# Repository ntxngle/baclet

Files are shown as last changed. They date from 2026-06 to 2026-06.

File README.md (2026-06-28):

# baclet
## What and Why

A mobile, battery powered trinket that measures BAC (Blood AlcoholContent) by tracking time and drinks you enter via the extraordinarly user friendly triple button system.

Obviously this is not a medical device. You input body params on setup, then can log each drink by volume and percentage, and it calculates BAC. It has chargering, a buzzer, USB serial, and a nice 1.28 OLED, all behind an auto-off switch to save power.

Being the science minded individual I am, I have always approached consumption of this nature from a data driven mindset: I logged, sometimes more honestly than others, my drinks, and monitored my BAC level in the app. While I wouldn't say this pastime is exactly a hobby or passion, it's a part of my life and I figured it would be fun to try to connect the two disciplines. Thats why I made this brilliant contraption.

## Photos








## How it works
Again to be clear this is not a breathalyzer. You enter the drinks manually. Then, based parameters you've entered like weight, gender, it calculates the BAC level via the widmark formula. 

Drink inputs are timestamped from RTC and put into flash storage so it can be access and included in calculations on wake.

It was designed to be a thin as possible, with all SMD compontents located on one side, and the screen and buttons on the other. Barring the battery, this could have easily been a centimeter wide, but of course I'm not apple and cannot afford a custom designed battery to fit in the free space perfectly. I'm quite proud of the PCB design however, its pretty compact for the time it took me to make.

## BOM
|name |quantity|Footprint |link |Price|
|---|---|---|---|-----|
|PCB |1 | |JLC files in repo |2 |
|Battery |1 | |https://es.aliexpress.com/item/1005012320035574.html|6 |
|Case |1 | |3d print it |1 |
|PCF8523T |1 |SOIC-8_3.9x4.9mm_P1.27mm |https://www.lcsc.com/product-detail/C2651516.html |1.19 |
|100k |8 |R_0603_1608Metric |https://www.lcsc.com/product-detail/C2906980.html |0.38 |
|RP2040 |1 |QFN-56-1EP_7x7mm_P0.4mm_EP3.2x3.2mm |https://www.lcsc.com/product-detail/C2040.html |0.99 |
|1N4148 |3 |D_SOD-323F |https://www.lcsc.com/product-detail/C2128.html |0.59 |
|TPS63900 |1 |WSON-10-1EP_2.5x2.5mm_P0.5mm_EP1.2x2mm_ThermalVias|https://www.lcsc.com/product-detail/C1518762.html |1.21 |
|W25Q32JVSS |1 |SOIC-8_5.3x5.3mm_P1.27mm |https://www.lcsc.com/product-detail/C179173.html |2.49 |
|NPN C22400355 |4 |SOT-23 |https://www.lcsc.com/product-detail/C22400355.html  |0.55 |
|2169900002 |1 |USB-SMD_2169900002 |https://www.lcsc.com/product-detail/C3197869.html |1.38 |
|2.2uH SRN3015TA-2R2M|1 |L_APV_ANR3010 |https://www.lcsc.com/product-detail/C5362464.html |0.61 |
|C20625731 |1 |Crystal_SMD_3225-4Pin_3.2x2.5mm |https://www.lcsc.com/product-detail/C20625731.html  |1.47 |
|USBLC6-2SC6 |1 |SOT-23-6 |https://www.lcsc.com/product-detail/C7519.html |0.87 |
|MLT-5020 |1 |BUZ-SMD_L5.0-W5.5-P4.60 |https://www.lcsc.com/product-detail/C94598.html |0.44 |
|MCP73831-2-OT |1 |SOT-23-5 |https://www.lcsc.com/product-detail/C635037.html |1.58 |
|B3F-1052 |3 |KEY-TH_4P-L6.0-W6.0-P4.50 |https://www.lcsc.com/product-detail/C87037.html |0.92 |
|HS13L03W2C01 |1 |OLED-TH_L35.4-W33.5_HS13L03W2C01 |https://www.lcsc.com/product-detail/C7465997.html |4.98 |
|Total | | | |32.54|

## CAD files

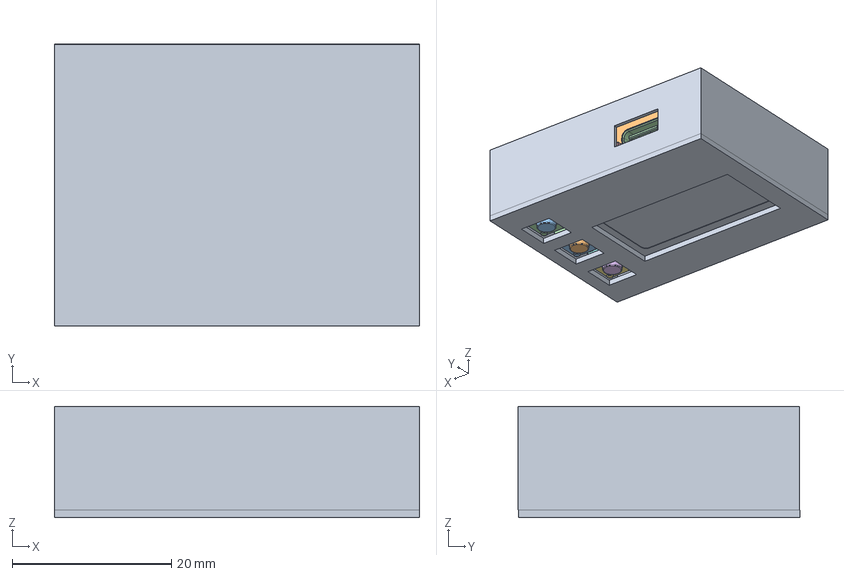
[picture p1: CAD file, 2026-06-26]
mechanical/baclet.FCStd
45.9 x 35.4 x 14.0 mm
QFN-56-1EP_7x7mm_P0.4mm_EP3.2x3.2mm
USB-SMD_2169900002
USB-SMD_2169900003
USB-SMD_2169900004
USB-SMD_2169900005
USB-SMD_2169900006
USB-SMD_2169900007
USB-SMD_2169900008
USB-SMD_2169900009
USB-SMD_2169900010
USB-SMD_2169900011
USB-SMD_2169900012
USB-SMD_2169900013
USB-SMD_2169900014
USB-SMD_2169900015
BUZ-SMD_3P-L5.2-W5.2-H2.0-P3.50
KEY-TH_4P-L6.0-W6.0-H4.3-LS6.5-P4.5
KEY-TH_4P-L6.0-W6.0-H4.3-LS6.5-P4.006
KEY-TH_4P-L6.0-W6.0-H4.3-LS6.5-P4.007
KEY-TH_4P-L6.0-W6.0-H4.3-LS6.5-P4.009
KEY-TH_4P-L6.0-W6.0-H4.3-LS6.5-P4.010
KEY-TH_4P-L6.0-W6.0-H4.3-LS6.5-P4.011
OLED-TH_L35.4-W33.5_HS13L03W2C01
KEY-TH_4P-L6.0-W6.0-H4.3-LS6.5-P4.013
KEY-TH_4P-L6.0-W6.0-H4.3-LS6.5-P4.014
KEY-TH_4P-L6.0-W6.0-H4.3-LS6.5-P4.015
bac_PCB

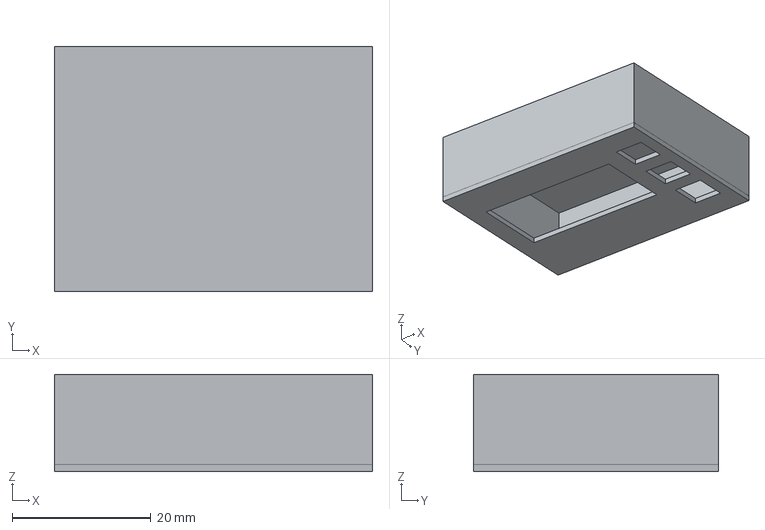
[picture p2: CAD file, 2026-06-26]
mechanical/case.step
45.9 x 35.4 x 14.0 mm

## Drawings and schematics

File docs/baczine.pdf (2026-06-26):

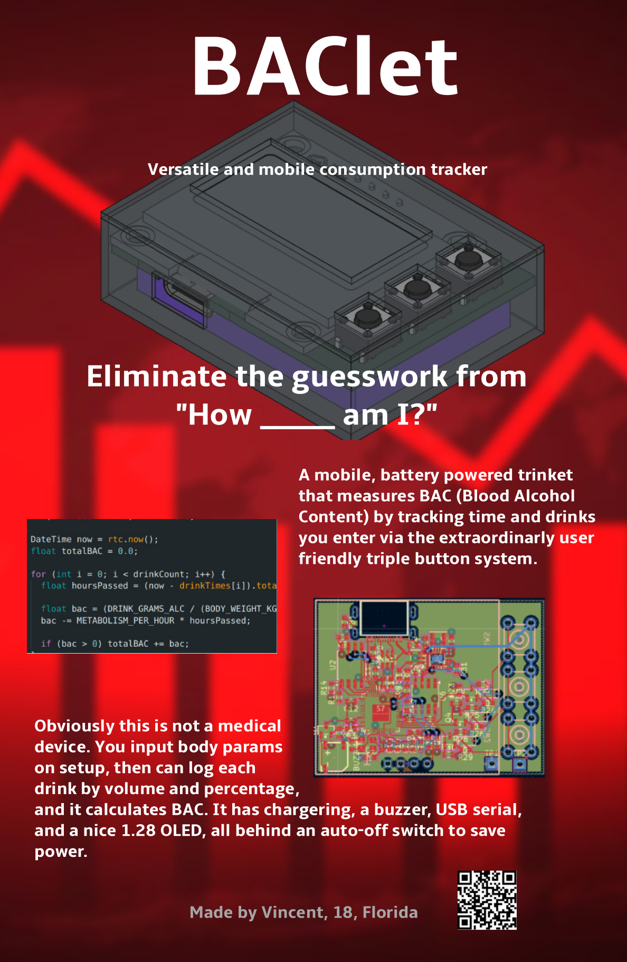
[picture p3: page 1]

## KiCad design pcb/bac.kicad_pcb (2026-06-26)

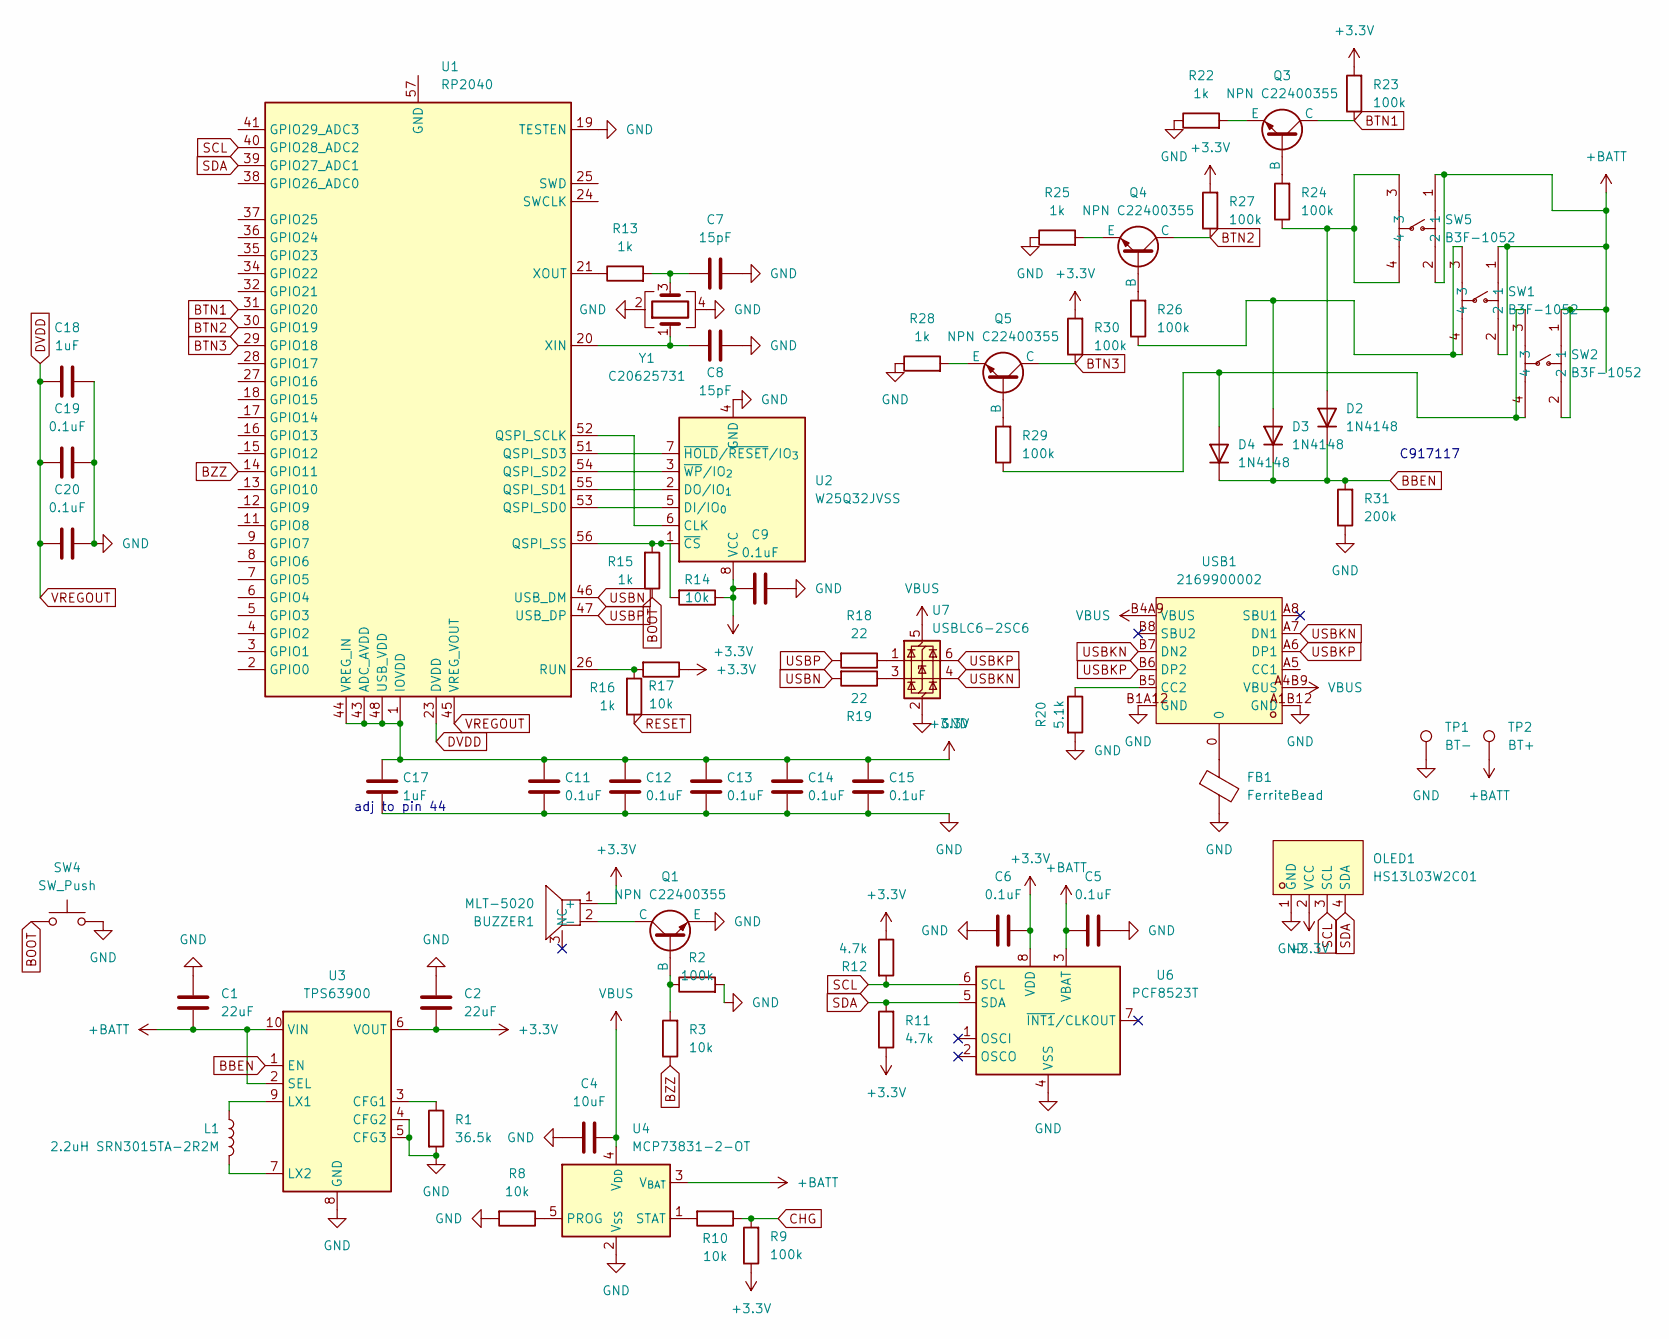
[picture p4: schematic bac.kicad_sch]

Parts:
BUZZER1: MLT-5020; BUZ-SMD_L5.0-W5.5-P4.60; MPN MLT-5020; LCSC Part C94598
C1, C2: 22uF; C_0603_1608Metric
C4: 10uF; C_0603_1608Metric
C5, C6, C9, C11, C12, C13, C14, C15, C19, C20: 0.1uF; C_0603_1608Metric
C7, C8: 15pF; C_0603_1608Metric
C17, C18: 1uF; C_0603_1608Metric
D2, D3, D4: 1N4148; D_SOD-323F
FB1: FerriteBead; L_0603_1608Metric
L1: 2.2uH SRN3015TA-2R2M; L_APV_ANR3010
OLED1: HS13L03W2C01; OLED-TH_L35.4-W33.5_HS13L03W2C01; MPN HS13L03W2C01; LCSC Part C7465997
Q1, Q3, Q4, Q5: NPN C22400355; SOT-23
R1: 36.5k; R_0603_1608Metric
R2, R9, R23, R24, R26, R27, R29, R30: 100k; R_0603_1608Metric
R3, R8, R10, R14, R17: 10k; R_0603_1608Metric
R11, R12: 4.7k; R_0603_1608Metric
R13, R15, R16, R22, R25, R28: 1k; R_0603_1608Metric
R18, R19: 22; R_0603_1608Metric
R20: 5.1k; R_0603_1608Metric
R31: 200k; R_0603_1608Metric
SW1, SW2, SW5: B3F-1052; KEY-TH_4P-L6.0-W6.0-P4.50; MPN B3F-1052; LCSC Part C87037
SW4: SW_Push
TP1: BT-; TestPoint_THTPad_2.0x2.0mm_Drill1.0mm
TP2: BT+; TestPoint_THTPad_2.0x2.0mm_Drill1.0mm
U1: RP2040; QFN-56-1EP_7x7mm_P0.4mm_EP3.2x3.2mm
U2: W25Q32JVSS; SOIC-8_5.3x5.3mm_P1.27mm
U3: TPS63900; WSON-10-1EP_2.5x2.5mm_P0.5mm_EP1.2x2mm_ThermalVias
U4: MCP73831-2-OT; SOT-23-5
U6: PCF8523T; SOIC-8_3.9x4.9mm_P1.27mm
U7: USBLC6-2SC6; SOT-23-6
USB1: 2169900002; USB-SMD_2169900002; MPN 2169900002; LCSC Part C3197869
Y1: C20625731; Crystal_SMD_3225-4Pin_3.2x2.5mm

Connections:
+3.3V: BUZZER1.1 (+), C2.1, C6.1, C9.2, C11.1, C12.1, C13.1, C14.1, C15.1, C17.1, OLED1.2 (VCC), R9.1, R11.1, R12.1, R14.1, R17.1, R23.2, R27.2, R30.2, U1.1 (IOVDD), U1.10 (IOVDD), U1.22 (IOVDD), U1.33 (IOVDD), U1.42 (IOVDD), U1.43 (ADC_AVDD), U1.44 (VREG_IN), U1.48 (USB_VDD), U1.49 (IOVDD), U2.8 (VCC), U3.6 (VOUT), U6.8 (VDD)
+BATT: C1.1, C5.2, SW1.1, SW1.2, SW2.1, SW2.2, SW5.1, SW5.2, TP2.1, U3.2 (SEL), U3.10 (VIN), U4.3 (V_{BAT}), U6.3 (VBAT)
BBEN: D2.1 (K), D3.1 (K), D4.1 (K), R31.2, U3.1 (EN)
BOOT: R15.1, SW4.1
BTN1: Q3.1 (C), R23.1, U1.31 (GPIO20)
BTN2: Q4.1 (C), R27.1, U1.30 (GPIO19)
BTN3: Q5.1 (C), R30.1, U1.29 (GPIO18)
BZZ: R3.1, U1.14 (GPIO11)
CHG: R9.2, R10.1
DVDD: C18.2, C19.2, C20.2, U1.23 (DVDD), U1.45 (VREG_VOUT), U1.50 (DVDD)
GND: C1.2, C2.2, C4.2, C5.1, C6.2, C7.1, C8.1, C9.1, C11.2, C12.2, C13.2, C14.2, C15.2, C17.2, C18.1, C19.1, C20.1, FB1.2, OLED1.1 (GND), Q1.3 (E), R1.2, R2.2, R8.2, R20.2, R22.1, R25.1, R28.1, R31.1, SW4.2, TP1.1, U1.19 (TESTEN), U2.4 (GND), U3.4 (CFG2), U3.5 (CFG3), U3.8 (GND), U3.11 (GND), U4.2 (V_{SS}), U6.4 (VSS), U7.2 (GND), USB1.A1B12 (GND), USB1.B1A12 (GND), Y1.2, Y1.4
unnamed: BUZZER1.2 (-), Q1.1 (C)
unnamed: C7.2, R13.2, Y1.3
unnamed: D2.2 (A), R24.1, SW5.3, SW5.4
unnamed: D3.2 (A), R26.1, SW1.3, SW1.4
unnamed: D4.2 (A), R29.1, SW2.3, SW2.4
unnamed: FB1.1, USB1.0
unnamed: Q1.2 (B), R2.1, R3.2
unnamed: Q3.2 (B), R24.2
unnamed: Q3.3 (E), R22.2
unnamed: Q4.2 (B), R26.2
unnamed: Q4.3 (E), R25.2
unnamed: Q5.2 (B), R29.2
unnamed: Q5.3 (E), R28.2
unnamed: R18.1, U7.1 (I/O1)
unnamed: R19.1, U7.3 (I/O2)
unnamed: U1.52 (QSPI_SCLK), U2.6 (CLK)
unnamed: U1.53 (QSPI_SD0), U2.5 (DI/IO_{0})
unnamed: U1.55 (QSPI_SD1), U2.2 (DO/IO_{1})
unnamed: U1.54 (QSPI_SD2), U2.3 (~WP/IO_{2})
unnamed: U1.51 (QSPI_SD3), U2.7 (~HOLD/~RESET/IO_{3})
unnamed: R14.2, R15.2, U1.56 (QSPI_SS), U2.1 (~CS)
unnamed: R16.2, R17.2, U1.26 (RUN)
unnamed: C8.2, U1.20 (XIN), Y1.1
unnamed: R13.1, U1.21 (XOUT)
unnamed: R1.1, U3.3 (CFG1)
unnamed: L1.2, U3.9 (LX1)
unnamed: L1.1, U3.7 (LX2)
unnamed: R8.1, U4.5 (PROG)
unnamed: R10.2, U4.1 (STAT)
unnamed: R20.1, USB1.B5 (CC2)
RESET: R16.1
SCL: OLED1.3 (SCL), R12.2, U1.40 (GPIO28_ADC2), U6.6 (SCL)
SDA: OLED1.4 (SDA), R11.2, U1.39 (GPIO27_ADC1), U6.5 (SDA)
USBKN: U7.4 (I/O2), USB1.A7 (DN1), USB1.B7 (DN2)
USBKP: U7.6 (I/O1), USB1.A6 (DP1), USB1.B6 (DP2)
USBN: R19.2, U1.46 (USB_DM)
USBP: R18.2, U1.47 (USB_DP)
VBUS: C4.1, U4.4 (V_{DD}), U7.5 (VBUS), USB1.A4B9 (VBUS), USB1.B4A9 (VBUS)

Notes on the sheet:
adj to pin 44
C917117

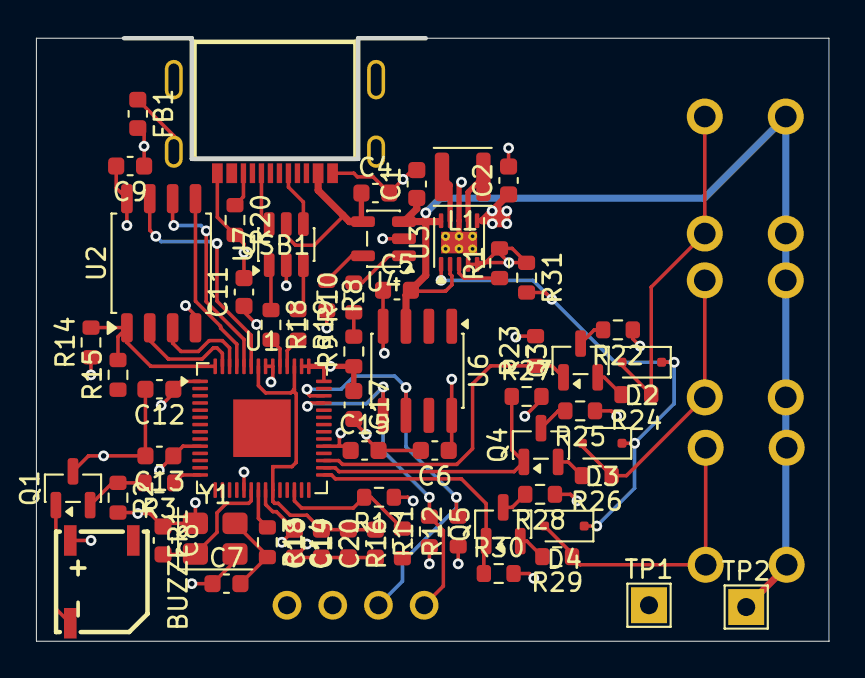
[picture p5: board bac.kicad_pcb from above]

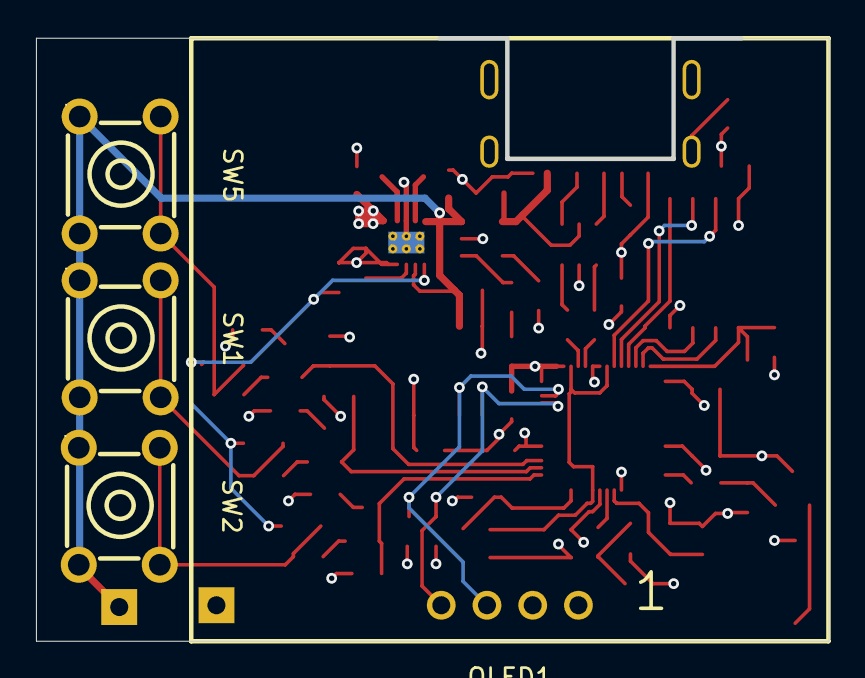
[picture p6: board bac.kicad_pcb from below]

Board: 4 copper layers, 44.0 x 33.5 mm, 67 parts (4 on the bottom side), 47 nets.

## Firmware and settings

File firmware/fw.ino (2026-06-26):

#include <Wire.h>
#include <RTClib.h>

RTC_DS3231 rtc;

const float BODY_WEIGHT_KG = 80.0;
const bool IS_MALE = true;
const float METABOLISM_PER_HOUR = 0.015;

const float R = IS_MALE ? 0.73 : 0.66;

const float DRINK_GRAMS_ALC = 14.0; 
const int BTN_ADD = 2;
const int BTN_SHOW = 3;
const int BTN_RESET = 4;

DateTime drinkTimes[20];
int drinkCount = 0;

void setup() {
  Serial.begin(115200);
  delay(2000);

  Wire.setSDA(16);
  Wire.setSCL(17);
  Wire.begin();

  if (!rtc.begin()) {
    Serial.println("RTC not found!");
    while (1);
  }

  pinMode(BTN_ADD, INPUT_PULLUP);
  pinMode(BTN_SHOW, INPUT_PULLUP);
  pinMode(BTN_RESET, INPUT_PULLUP);

  Serial.println("BAC Calculator Ready");
}

float computeBAC() {
  if (drinkCount == 0) return 0.0;

  DateTime now = rtc.now();
  float totalBAC = 0.0;

  for (int i = 0; i < drinkCount; i++) {
    float hoursPassed = (now - drinkTimes[i]).totalseconds() / 3600.0;

    float bac = (DRINK_GRAMS_ALC / (BODY_WEIGHT_KG * R)) * 100.0;
    bac -= METABOLISM_PER_HOUR * hoursPassed;

    if (bac > 0) totalBAC += bac;
  }

  return totalBAC;
}

void loop() {
  if (!digitalRead(BTN_ADD)) {
    if (drinkCount < 20) {
      drinkTimes[drinkCount++] = rtc.now();
      Serial.print("Drink added. Total drinks: ");
      Serial.println(drinkCount);
      delay(300);
    }
  }

  if (!digitalRead(BTN_SHOW)) {
    float bac = computeBAC();
    Serial.print("Current BAC: ");
    Serial.println(bac, 4);
    delay(300);
  }

  if (!digitalRead(BTN_RESET)) {
    drinkCount = 0;
    Serial.println("Session reset.");
    delay(300);
  }
}
